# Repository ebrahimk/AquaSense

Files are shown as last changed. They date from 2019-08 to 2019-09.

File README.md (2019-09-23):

# AquaSense

#### University of Zürich H2K Group and Oregon State University OPEnS Lab 
#### PI: Dr. Jan Seibert &  Dr.Ilja van Meerveld 
###### Team Leads: Kamron Ebrahimi, Jose Manuel Lopez Alcala

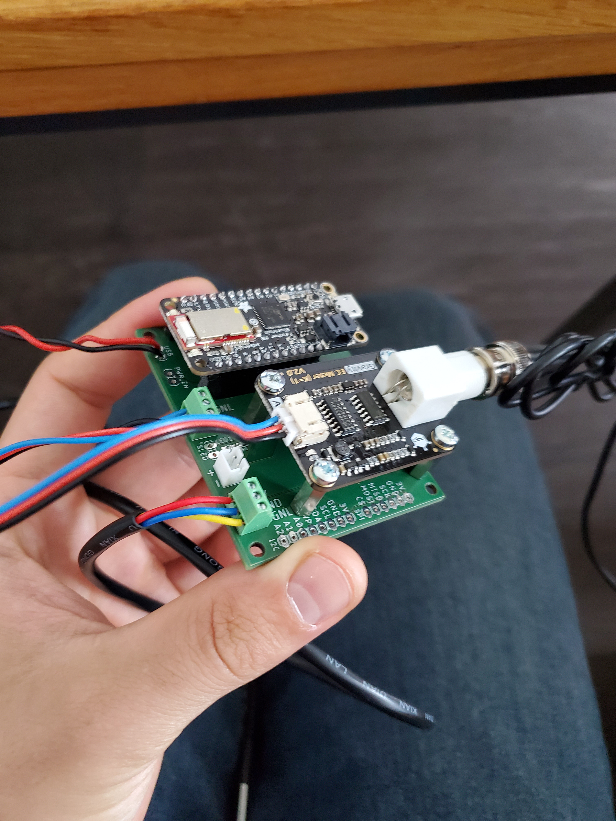
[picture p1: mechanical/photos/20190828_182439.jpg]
AquaSense


## About

AquaSense is a low-cost sensor system capable of measuring electrical conductivity (EC) and relative temperature (RT) of water streams. The device connects via Bluetooth to the AquaSense App, available for Android and iOS, capable of displaying a live feed of collected data and remotely configuring the sampling interval of the device for time series of varying resolutions.

Its primary users are people who are considered “super users” of the CrowdWater platform, a citizen science project sponsored by the University of Zurich intended to collect hydrological data including water level, streamflow, and soil moisture. “Super users” are individuals with more experience with the data collection processes and long term use of the application. These individuals would be sent an AquaSense system that they could use while they are surveying water streams using the CrowdWater application. 

The primary uses are for water hydrological characterization of streams, but it can be used as a teaching tool for emerging hydrology students, as well. As a researcher, having a tool that helps characterize the stream very quickly is extremely beneficial as the hand calculations and lab equipment need for this characterization will be expedited by this instrument. One application, other than EC and RT, is the estimation of water flow based on the concentration of the conductivity over time. This kind of sampling is also crucial characterization for a stream and can be easily estimated using an AquaSense instrument. As a student, this instrument can be beneficial as a way to materialize the theory learned in the classroom. The AquaSense application also aims to have an educational version where only the minimal data is collected for characterization and the calculations are left as an exercise for the student. 
The principle on which AquaSense works is based on electrical conductivity as an indicator of the ion content of the water and thus affecting the water’s ability to conduct an electrical current. An ion’s conductivity is temperature-dependent and for that reason, the system must be calibrated to the temperature of the water that is being sampled or have a temperature sensor that compensates the electrical conductivity readings. AquaSense is equipped with a temperature sensor probe so that users do not have to worry about doing a temperature compensation while in the field. Only a two-point calibration is needed before starting and this is done by putting the probe in two solutions of known conductivity and the system does all the calculations to calibrate the probe to the proper level.

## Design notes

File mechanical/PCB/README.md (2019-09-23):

This folder contains the EAGLE files that were created for the PCB of the AquaSense.

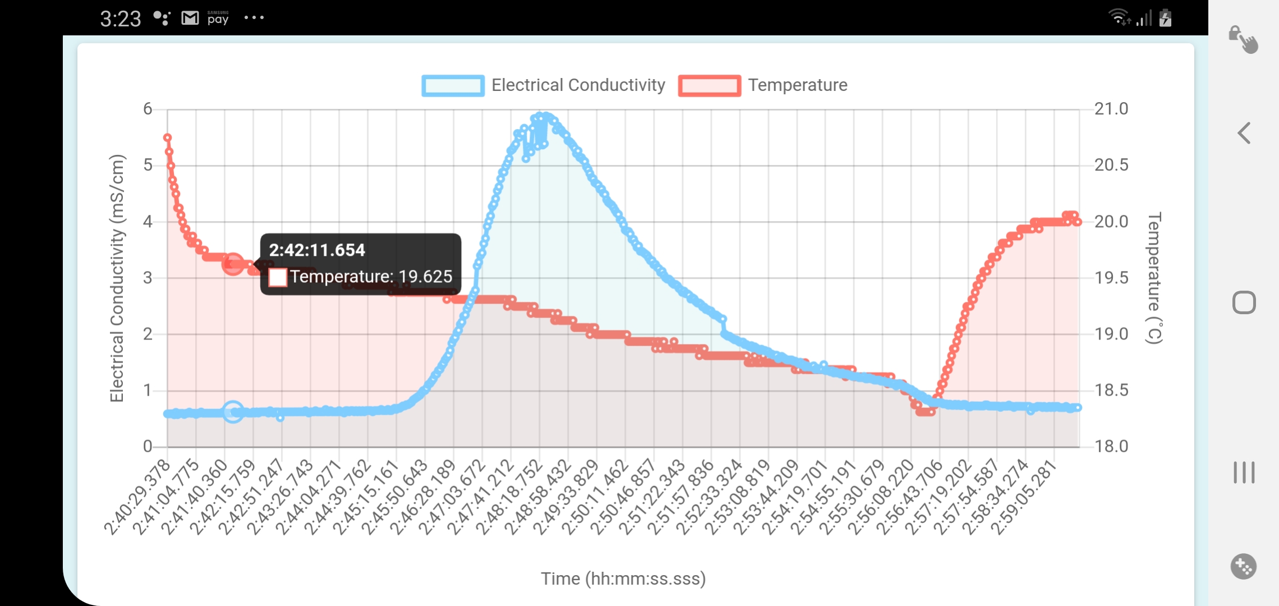
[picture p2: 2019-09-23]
mechanical/photos/Screenshot_20190830-152322_AquaSense.jpg

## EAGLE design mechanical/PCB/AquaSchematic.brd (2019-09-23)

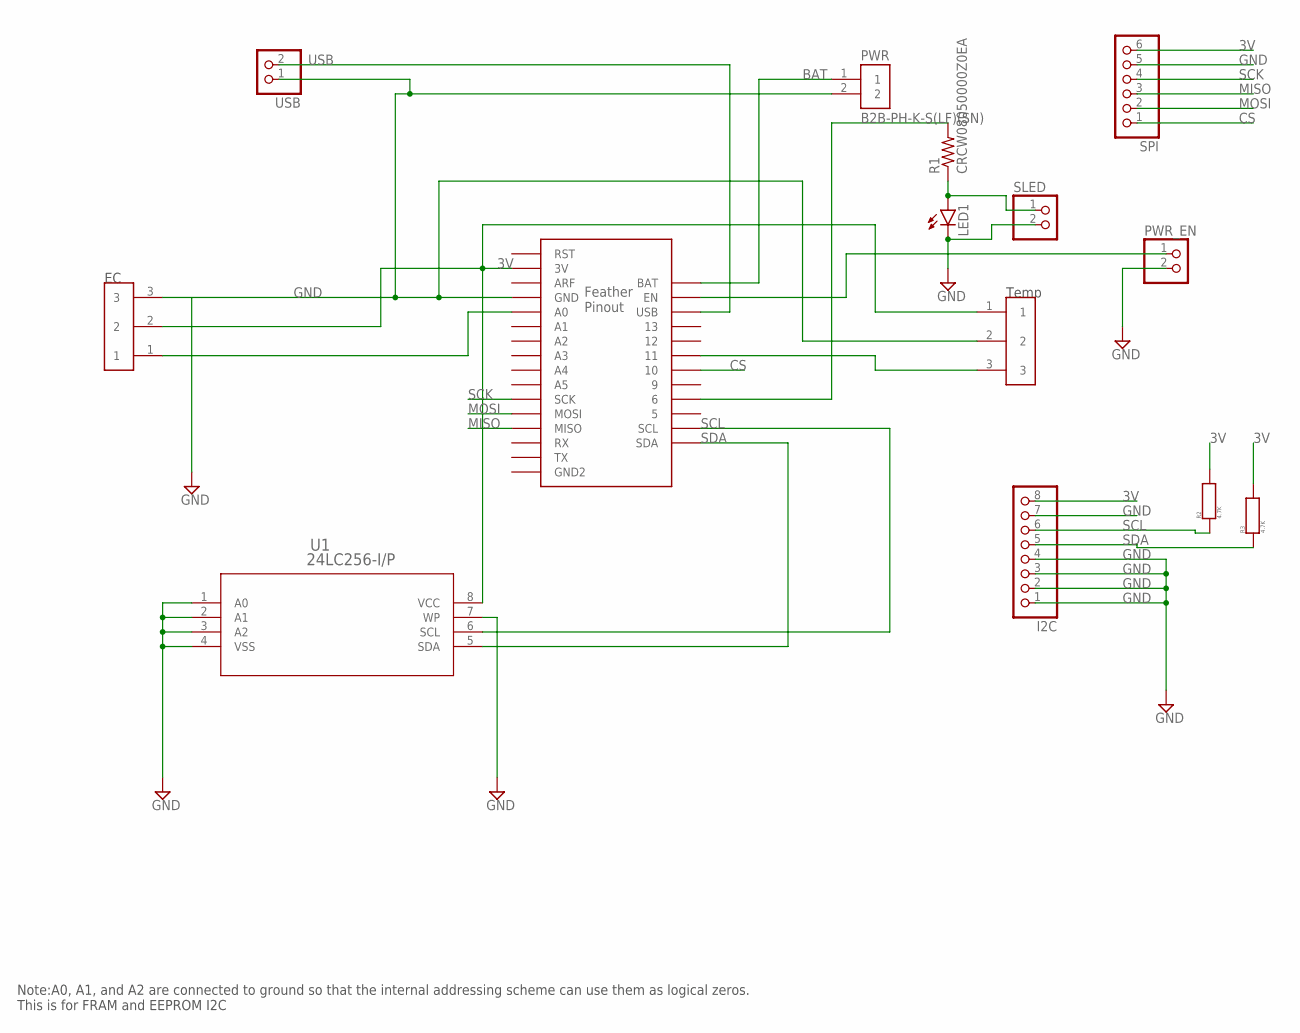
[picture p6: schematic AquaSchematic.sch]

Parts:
EC: 39773-0003
I2C: PINHD-1X8; 1X08
LED1: LEDCHIP-LED0805; CHIP-LED0805
PWR: B2B-PH-K-S(LF)(SN); JST_B2B-PH-K-S(LF)(SN)
PWR_EN: PINHD-1X2; 1X02
R1: CRCW08050000Z0EA; RES_0805
R2, R3: 4.7K; MFR3-4K7FC
SLED: PINHD-1X2; 1X02
SPI: PINHD-1X6; 1X06
TEMP: 39773-0003
U1: 24LC256-I/P; PDIP8_300MC
U$1: FEATHER_M0_PROTO; FEATHER_MO_PROTO
USB: PINHD-1X2; 1X02

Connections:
3V: EC.2, I2C.8, R2.PIN1, R3.PIN1, SPI.6, TEMP.1, U1.8 (VCC), U$1.3V
BAT: PWR.1, U$1.BAT
CS: SPI.1, U$1.10
EN: PWR_EN.1, U$1.EN
GND: EC.3, I2C.1, I2C.2, I2C.3, I2C.4, I2C.7, LED1.C, PWR.2, PWR_EN.2, SLED.2, SPI.5, TEMP.2, U1.1 (A0), U1.2 (A1), U1.3 (A2), U1.4 (VSS), U1.7 (WP), U$1.GND, USB.1
MISO: SPI.3, U$1.MISO
MOSI: SPI.2, U$1.MOSI
unnamed: LED1.A, R1.1, SLED.1
unnamed: R1.2, U$1.6
unnamed: EC.1, U$1.A0
unnamed: TEMP.3, U$1.11
SCK: SPI.4, U$1.SCK
SCL: I2C.6, R2.PIN2, U1.6 (SCL), U$1.SCL
SDA: I2C.5, R3.PIN2, U1.5 (SDA), U$1.SDA
USB: U$1.USB, USB.2

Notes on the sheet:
Note:A0, A1, and A2 are connected to ground so that the internal addressing scheme can use them as logical zeros. This is for FRAM and EEPROM I2C
Temp

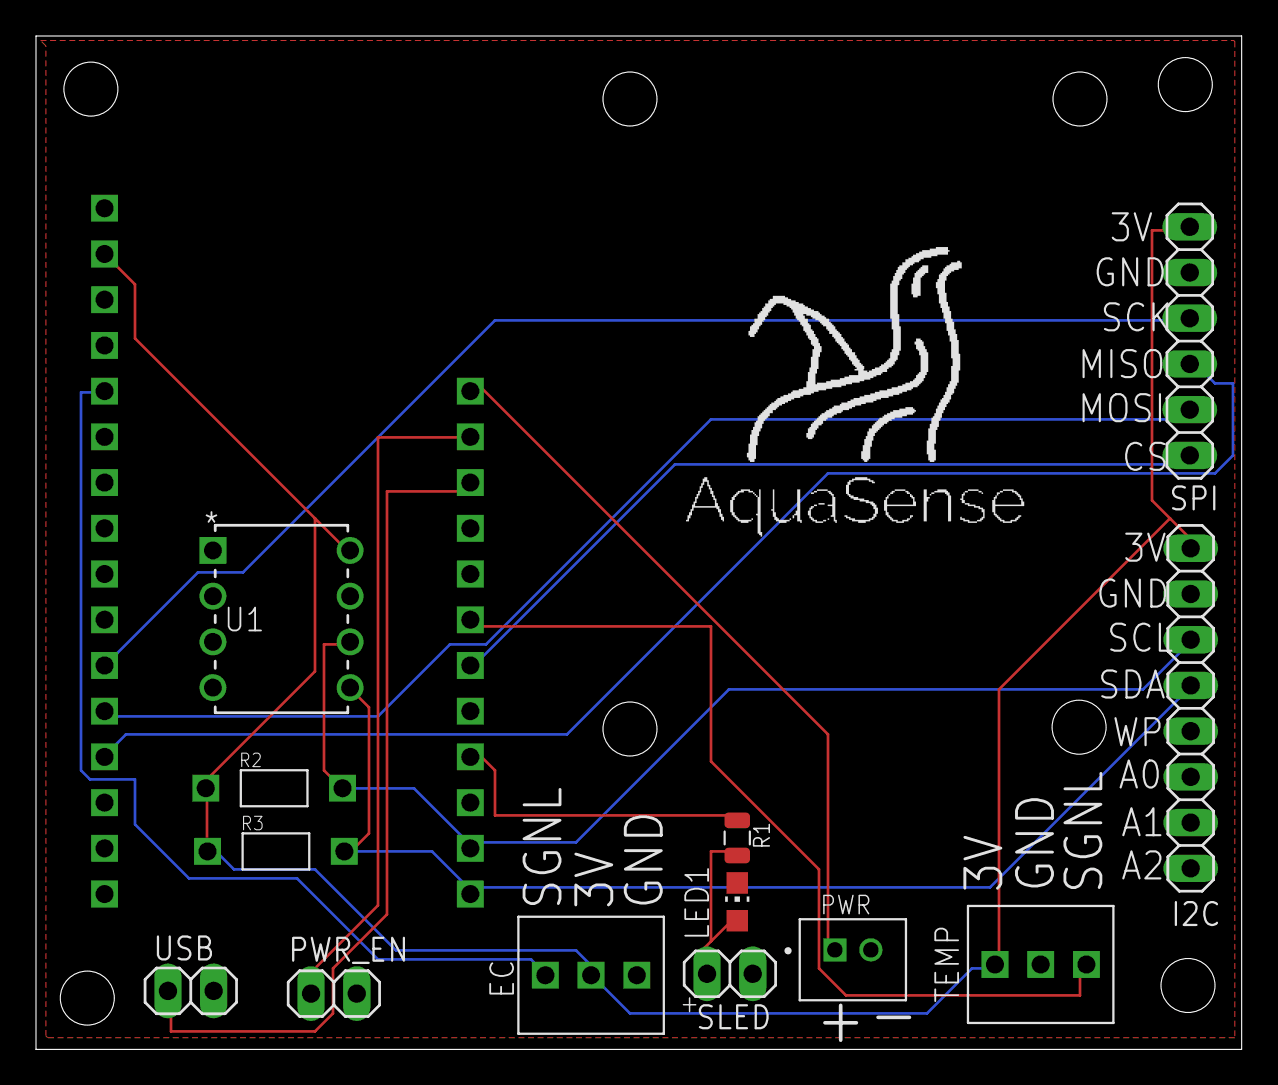
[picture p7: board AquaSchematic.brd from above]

Board: 2 copper layers, 67.0 x 56.3 mm, 14 parts (0 on the bottom side), 15 nets.

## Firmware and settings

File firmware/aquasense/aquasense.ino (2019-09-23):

/*
 * AquaSense
 * University of Zurich and  Oregon State University OPEnS Lab
 * Summer 2k19
 * Authors: Jose Manuel Lopez Alcala & Kamron Ebrahimi
 * 
 */

#include <Arduino.h>
#include <SPI.h>
#include "Adafruit_BLE.h"
#include "Adafruit_BluefruitLE_SPI.h"
#include "Adafruit_BluefruitLE_UART.h"
#include <math.h>
#include <CRC.h>        // MODEBUS 16-bit checksum
#include "DFRobot_EC.h"
#include <m0EEPROM.h>
#include <OneWire.h>
#include <DallasTemperature.h>
#include "BluefruitConfig.h"

#if SOFTWARE_SERIAL_AVAILABLE
#include <SoftwareSerial.h>
#endif

#define FACTORYRESET_ENABLE 1
#define MINIMUM_FIRMWARE_VERSION "0.6.6"
#define MODE_LED_BEHAVIOUR "MODE"
#define VBATPIN A7
#define ONE_WIRE_BUS 11 
#define EC_PIN A0
#define LEDPIN 6


Adafruit_BluefruitLE_SPI ble(BLUEFRUIT_SPI_CS, BLUEFRUIT_SPI_IRQ, BLUEFRUIT_SPI_RST);
OneWire oneWire(ONE_WIRE_BUS);
DallasTemperature sensors(&oneWire);
DeviceAddress insideThermometer;

unsigned long EC_timer = millis();
uint16_t EC_timeout = 1000;
unsigned long bat_timer = millis();
unsigned long poll_timer = millis(); 
uint16_t bat_timeout = 500;
bool LED_on = true;
bool low_bat; 
bool logData;
float voltage,ecValue,temperature = 25;
DFRobot_EC ec;
int count = 0;

void setup(void)
{
  pinMode(LEDPIN, OUTPUT);
  digitalWrite(LEDPIN, HIGH);
  Serial.begin(115200);
  if (!ble.begin(VERBOSE_MODE))
  {
    error(F("Couldn't find Bluefruit, make sure it's in CoMmanD mode & check wiring?"));
  }

  if (FACTORYRESET_ENABLE)
  {
    /* Perform a factory reset to make sure everything is in a known state */
    Serial.println(F("Performing a factory reset: "));
    if (!ble.factoryReset())
    {
      error(F("Couldn't factory reset"));
    }
  }
  

  /* Disable command echo from Bluefruit */
  ble.echo(false);
  ble.sendCommandCheckOK("AT+GAPDEVNAME=AquaSense");
  Serial.println("Requesting Bluefruit info:");
  ble.info();
  ble.verbose(false); 

  Serial.println(F("******************************"));

  // LED Activity command is only supported from 0.6.6
  if (ble.isVersionAtLeast(MINIMUM_FIRMWARE_VERSION))
  {
    // Change Mode LED Activity
    ble.sendCommandCheckOK("AT+HWModeLED=" MODE_LED_BEHAVIOUR);
  }

  // Set module to DATA mode
  ble.setMode(BLUEFRUIT_MODE_DATA);

  // Set data logging to false
  logData = false;

  //Start  the Electrical Conductivity sensor
  ec.begin();

  //Start up the Temeperature sensor
  sensors.begin();
  sensors.getAddress(insideThermometer,0);

  // set the resolution to 12 bit (Each Dallas/Maxim device is capable of several different resolutions)
  sensors.setResolution(insideThermometer, 12);

}

void loop(void)
{
  char n, dataOut[BUFSIZE + 1], dataIn[1028];
  clearMemory(dataOut);
  clearMemory(dataIn);
  
  // Check to send EC data
  if (millis() - EC_timer >= EC_timeout && logData)
  {
    dtostrf(readEC(), 4, 4, dataOut);
    append(dataOut, '#');
    dtostrf(readTemperature(), 3, 3, dataOut + strlen(dataOut));
    addChksum(dataOut);
    printData(count, dataOut);
    ble.println(dataOut);
    count++;
    EC_timer = millis();
  }

  if (millis() - bat_timer >= bat_timeout && low_bat)
  {
    if(LED_on)
      digitalWrite(LEDPIN, LOW);
    else
       digitalWrite(LEDPIN, HIGH);
    LED_on = !LED_on;
    bat_timer = millis();
  }

  // Echo received data
  if (ble.available())
  {
    while (ble.available())
    {
      char c = ble.read();
      append(dataIn, c);
    }
    switch (dataIn[0])
    {
    case '!': // restart
      logData = true;
      break;
    case '#': // stop
      logData = false;
      break;
    case 'E': // Electrical conductivity update rate
      sscanf(dataIn + 1, "%d", &EC_timeout);
      Serial.print("NEW TIMEOUT EC: ");
      Serial.println(EC_timeout);
      break;
    }
  }
  ec.calibration(voltage,temperature);  // calibration process by Serail CMD

  // read the battery voltage and set LED blinking behavior
  if(millis() - poll_timer >= 2000){
      readBat();
      poll_timer = millis();
  }
}

void error(const __FlashStringHelper *err)
{
  Serial.println(err);
  while (1)
    ;
}

double getSinc(double x)
{
  return ((sin(x) * 3.14) / (3.14 * x));
}

void append(char s[], char c)
{
  int len = strlen(s);
  s[len] = c;
  s[len + 1] = '\0';
}

char *dtostrf(double val, signed char width, unsigned char prec, char *sout)
{
  char fmt[20];
  sprintf(fmt, "%%%d.%df", width, prec);
  sprintf(sout, fmt, val);
  return sout;
}

void addChksum(char *data)
{
  uint16_t chksum = CRC::crc16((uint8_t *)data, strlen(data));
  Serial.print("Checksum: ");
  Serial.println(chksum, HEX);
  strcat(data, "*");
  sprintf(data + strlen(data), "%x", chksum);
}

byte stringChecksum(char *s)
{
  byte c = 0;
  while (*s != '\0')
    c ^= *s++;
  return c;
}

float readEC()
{
  voltage = analogRead(EC_PIN)/1024.0*3300;  // read the voltage
  temperature = readTemperature();  // read your temperature sensor to execute temperature compensation
  ecValue =  ec.readEC(voltage,temperature);  // convert voltage to EC with temperature compensation
  return ecValue;
}

float readTemperature()
{
  sensors.requestTemperatures(); 
  float tempC = sensors.getTempCByIndex(0);
  return tempC;
}


void clearMemory(char *str)
{
  memset(str, '\0', sizeof(char) * strlen(str));
}

void printData(int count, char *data)
{
  Serial.print(count);
  Serial.print(": ");
  Serial.println(data);
}

void readBat(){
  float measuredvbat = analogRead(VBATPIN);
  measuredvbat *= 2;    // we divided by 2, so multiply back
  measuredvbat *= 3.3;  // Multiply by 3.3V, our reference voltage
  measuredvbat /= 1024; // convert to voltage
  if(measuredvbat < 3.5)
    low_bat = true;
  else
    low_bat = false;
}

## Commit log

2019-08-19 added temperature graph, formatted EC and temperature graphs, stop and start funcitonality
2019-08-20 communication between peripheral and central device successful
2019-08-22 Arduino is now sending sinc function which is getting uploaded to graph
2019-08-25 implemented 16 bit checksums tested up to 20 ms update rate, and wired all user input to Arduino
2019-08-25 mobile app now configures the ble device in real time
2019-08-29 Integrated EC and temperature sensing in firmware and built for ios, known issues will be documented in the README
    [aquasense.ino]
2019-09-23 added pcb files
    [AquaSchematic.brd, AquaSchematic.sch]
